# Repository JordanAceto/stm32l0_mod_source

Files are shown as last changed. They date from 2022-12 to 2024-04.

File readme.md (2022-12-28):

## Small STM32L0 based modulation source PCB

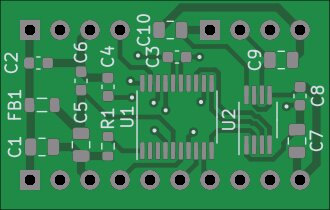
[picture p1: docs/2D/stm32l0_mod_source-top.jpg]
PCB front
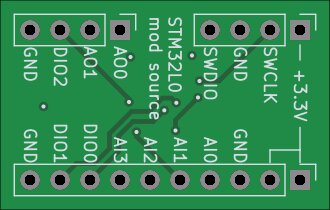
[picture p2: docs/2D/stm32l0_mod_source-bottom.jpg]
PCB rear
  

### Features:
- tiny pcb
- four analog inputs
- three digital input/outputs
- two analog outputs
- it can be configured for various modulation duties, such as
    - a dual LFO
    - a single ADSR
    - other things?
- drop it into various projects that need a small modulation source

### Status:

Task | Status |
---------|--------------|
Schematic capture | &#9745;
PCB layout | &#9745;
Test build | &#9745;
Safe to order boards| &#9745;

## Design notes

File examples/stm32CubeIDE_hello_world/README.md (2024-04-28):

# STM32CubeIDE "Hello World" example

## Brief
- This example is intended to exercise all of the IO pins on the board to verify everything works
- It is not intended as a real world project that does anything useful
- It does serve as an example of how to read and write analog and digital signals and write to the DAC
- It's an STM32CubeIDE project

## Description
This demo writes two low frequency analog ramp signals via the MCP4822 2-channel DAC.

Each ramp has:
- Variable frequency controlled by an analog signal in [0v, +3.3v]
- Variable offset controlled by an analog signal in [0v, +3.3v]
- The ability to "freeze" the ramp with a digital pin
  - Low = free running, high = frozen (the ramp stays at its current value until unfrozen)

The analog input signals can be driven by potentiometers wired as voltage dividers across the +3v3 rail, or any other convenient CV source that is in [0v, +3.3v].

## Pinouts

| PCB pin (silkscreen) | STM32 pin | Function |
|---|---|---|
| AI0 | PA0 | Rate A CV |
| AI1 | PA1 | Offset A CV |
| AI2 | PA2 | Rate B CV |
| AI3 | PA3 | Offset B CV |
| DOI0 | PA10 | Freeze A |
| DIO1 | PA9 | Freeze B |
| DIO2 | PA6 | CLK out (*f* = sample-rate / 2) |
| AO0 | - | Ramp A out, MCP4822 channel A |
| AO1 | - | Ramp B out, MCP4822 channel B |

### Schematic view of connections
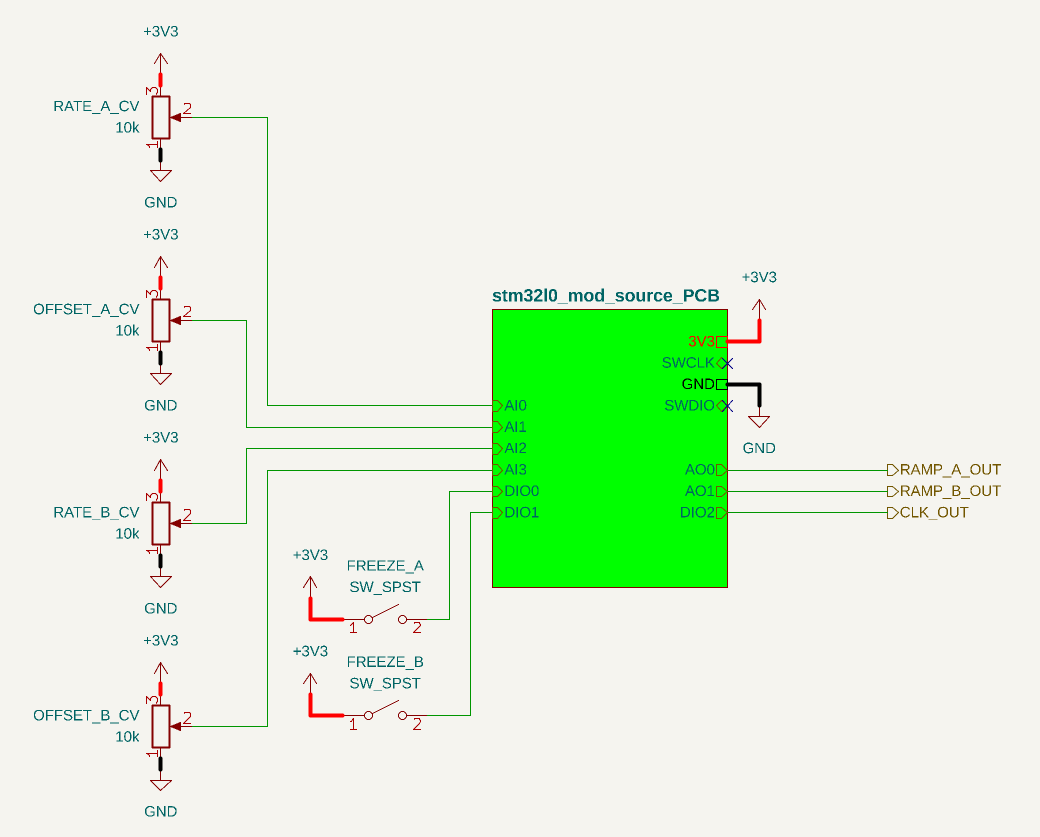
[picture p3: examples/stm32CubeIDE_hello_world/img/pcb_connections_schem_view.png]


### STM32CubeIDE view of connections
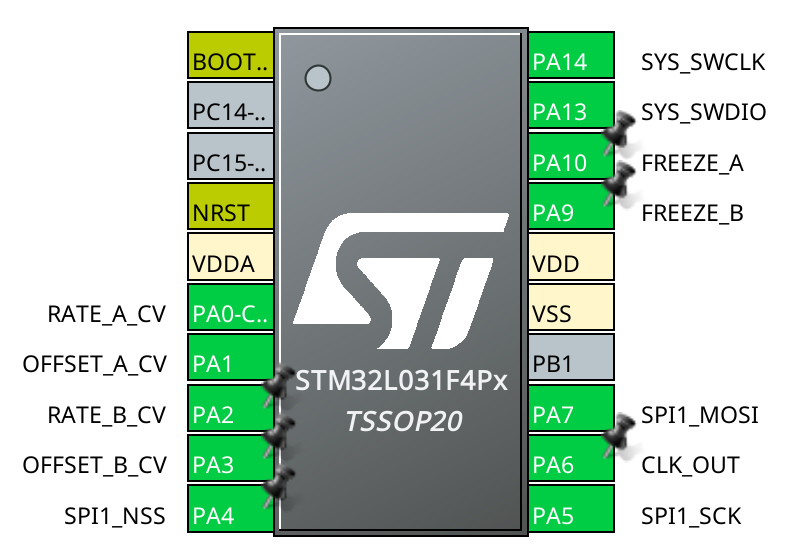
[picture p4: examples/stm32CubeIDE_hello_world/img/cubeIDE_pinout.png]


### Example breadboard setup
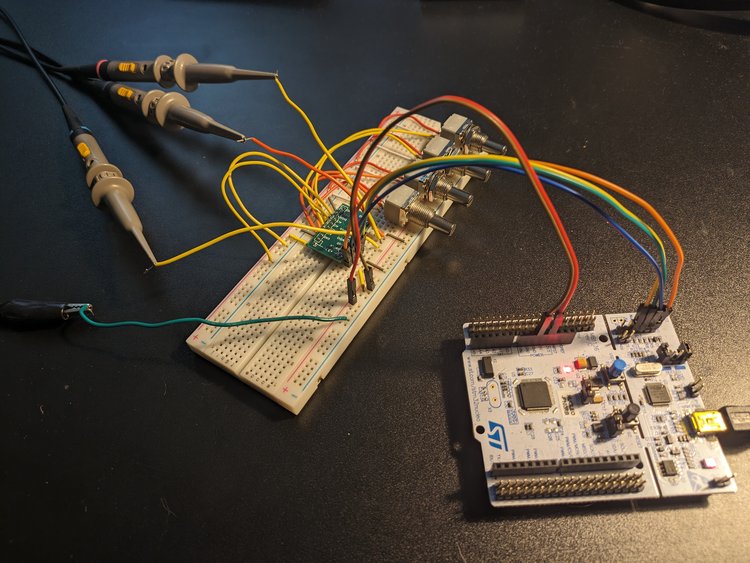
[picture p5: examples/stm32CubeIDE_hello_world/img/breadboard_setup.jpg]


## To verify
- Connect up the board as shown above, using a breadboard or other convenient method
- Flash the STM32L0 microcontroller with an STlink using the SWCLK and SWDIO pins
- Monitor the AO0, AO1, and DIO2 pins with an oscilloscope
- Verify that twiddling the pots alters the frequency and offset of the ramp signals
- Verify that pulling the FREEZE pins high freezes the associated ramp, and that the ramp resumes when the FREEZE pin is pulled low again 
- Verify that the CLK out on DIO2 is a square wave at 500Hz (default value)

Note that in the breadboard setup shown above, I am powering the board under test with a Nucleo acting as an STLink. This can be a convenient way to set up a minimal test.

Also note that I'm just using jumper wires jammed into the breadboard as the FREEZE switches.

## STM32CubeIDE Project Structure
This is a C++ CubeIDE project. The simplified project tree is shown below:

```
.
├── app
│   ├── app_main.cpp
│   └── app_main.hpp
├── lib
│   ├── analog_signals.cpp
│   ├── analog_signals.hpp
│   ├── MCP4822.cpp
│   └── MCP4822.hpp
├── Core
│   └── STM32 autogenerated Core .h and .c files
├── Drivers
│   └── STM32 provided CMSIS and driver files
├── L031F4Px_hello_world_example.ioc
└── STM32L031F4PX_FLASH.ld
```
User code is placed in `app` and `lib`. The `lib` directory contains user library files, `app` contains the main user application entry point. You shouldn't need to touch anything in `Core/` or `Drivers/` unless you want to change the pin or clock configuration.

The main application entry point function `app_main()` is called by the autogenerated `main()` function defined in `Core/Src/main.c` before the `while(1)` loop starts.

This allows us to keep our main application code separate from the CubeIDE autogenerated code. In my opinion this is cleaner than placing user code in the user-code-guards in the STM32 generated files.

### DMA note
The potentiometers are continuously read by the ADC and stored in a buffer via DMA. There are other ways to read the pots, this is one example of how you can scan a few pots.

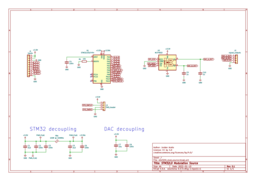
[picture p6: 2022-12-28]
docs/html_nav/images/cat_Schematic_stm32l0_mod_source-schematic.png

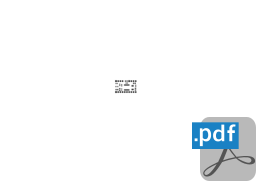
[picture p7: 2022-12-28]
docs/html_nav/images/cat_pdf_layers_stm32l0_mod_source-F_Mask.png

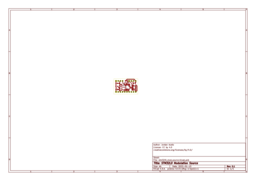
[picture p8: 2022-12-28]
docs/html_nav/images/cat_PCB_stm32l0_mod_source-F_Cu.png

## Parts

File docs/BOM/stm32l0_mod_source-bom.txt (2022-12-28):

Row	Description	Part	References	Value	Footprint	Quantity Per PCB	Status	Datasheet
1	Unpolarized capacitor	C	C2 C3 C4 C6 C8	100n	C_0603_1608Metric	5	 	~
2	Unpolarized capacitor	C	C9 C10	1u	C_0805_2012Metric	2	 	~
3	Unpolarized capacitor	C	C1 C5	2u2	C_0805_2012Metric	2	 	~
4	Unpolarized capacitor	C	C7	10u	C_0805_2012Metric	1	 	~
5	Ferrite bead, small symbol	FerriteBead_Small	FB1	100R @ 100MHz	L_0805_2012Metric	1	 	~
6	Generic connector, single row, 01x10, script generated (kicad-library-utils/schlib/autogen/connector/)	Conn_01x10	J1	inputs	PinHeader_1x10_P2.54mm_Vertical	1	 	~
7	Generic connector, single row, 01x04, script generated (kicad-library-utils/schlib/autogen/connector/)	Conn_01x04	J2 J3	signal_outputs	PinHeader_1x04_P2.54mm_Vertical	2	 	~
8	Resistor	R	R1	10k	R_0603_1608Metric	1	 	~
9	2-Channel 12-Bit D/A Converters with SPI Interface and Internal Reference (2.048V)	MCP4822	U2	MCP4822	MSOP-8_3x3mm_P0.65mm	1	 	http://ww1.microchip.com/downloads/en/DeviceDoc/20002249B.pdf
10	ARM Cortex-M0+ MCU, 16KB flash, 8KB RAM, 32MHz, 1.65-3.6V, 15 GPIO, TSSOP-20	STM32L031F4Px	U1	STM32L031F4Px	TSSOP-20_4.4x6.5mm_P0.65mm	1	 	http://www.st.com/st-web-ui/static/active/en/resource/technical/document/datasheet/DM00140359.pdf

Project info:
Schematic:	stm32l0_mod_source
Variant:	default
Revision:	0.1
Date:	2022-01-15
KiCad Version:	6.0.5+dfsg-1~bpo11+1
Statistics:
Component Groups:	10
Component Count:	17 (14 SMD/ 3 THT)
Fitted Components:	17 (14 SMD/ 3 THT)
Number of PCBs:	1
Total Components:	17

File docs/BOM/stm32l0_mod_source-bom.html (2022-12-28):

 | KiBot Bill of Materials
 | Schematic: stm32l0_mod_source Variant: default Revision: 0.1 Date: 2022-01-15 KiCad Version: 6.0.5+dfsg-1~bpo11+1 | Component Groups: 10 Component Count: 17 (14 SMD/ 3 THT) (per PCB) Fitted Components: 17 (14 SMD/ 3 THT) (per PCB) Number of PCBs: 1 Total Components: 17 (for 1 PCBs)
Row | Description | Part | References | Value | Footprint | Quantity Per PCB | Status | Datasheet
1 | Unpolarized capacitor | C | C2 C3 C4 C6 C8 | 100n | C_0603_1608Metric | 5 |  | ~
2 | Unpolarized capacitor | C | C9 C10 | 1u | C_0805_2012Metric | 2 |  | ~
3 | Unpolarized capacitor | C | C1 C5 | 2u2 | C_0805_2012Metric | 2 |  | ~
4 | Unpolarized capacitor | C | C7 | 10u | C_0805_2012Metric | 1 |  | ~
5 | Ferrite bead, small symbol | FerriteBead_Small | FB1 | 100R @ 100MHz | L_0805_2012Metric | 1 |  | ~
6 | Generic connector, single row, 01x10, script generated (kicad-library-utils/schlib/autogen/connector/) | Conn_01x10 | J1 | inputs | PinHeader_1x10_P2.54mm_Vertical | 1 |  | ~
7 | Generic connector, single row, 01x04, script generated (kicad-library-utils/schlib/autogen/connector/) | Conn_01x04 | J2 J3 | signal_outputs | PinHeader_1x04_P2.54mm_Vertical | 2 |  | ~
8 | Resistor | R | R1 | 10k | R_0603_1608Metric | 1 |  | ~
9 | 2-Channel 12-Bit D/A Converters with SPI Interface and Internal Reference (2.048V) | MCP4822 | U2 | MCP4822 | MSOP-8_3x3mm_P0.65mm | 1 |  | http://ww1.microchip.com/downloads/en/DeviceDoc/20002249B.pdf
10 | ARM Cortex-M0+ MCU, 16KB flash, 8KB RAM, 32MHz, 1.65-3.6V, 15 GPIO, TSSOP-20 | STM32L031F4Px | U1 | STM32L031F4Px | TSSOP-20_4.4x6.5mm_P0.65mm | 1 |  | http://www.st.com/st-web-ui/static/active/en/resource/technical/document/datasheet/DM00140359.pdf
Color reference:
KiCad Fields (default)
Generated Fields
User Fields
Empty Fields

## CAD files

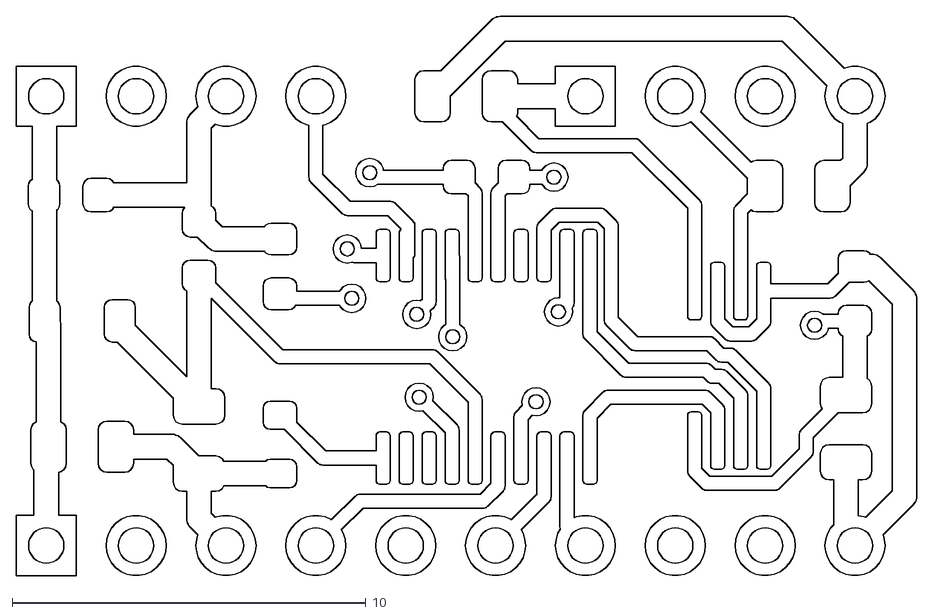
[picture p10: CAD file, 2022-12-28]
docs/CAD/stm32l0_mod_source-F_Cu.dxf
25.5 x 15.8

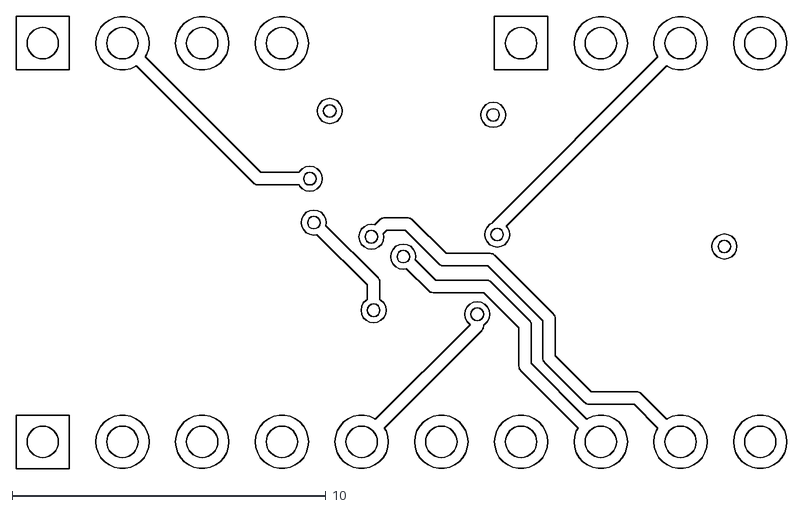
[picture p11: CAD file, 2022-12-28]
docs/CAD/stm32l0_mod_source-B_Cu.dxf
24.6 x 14.4

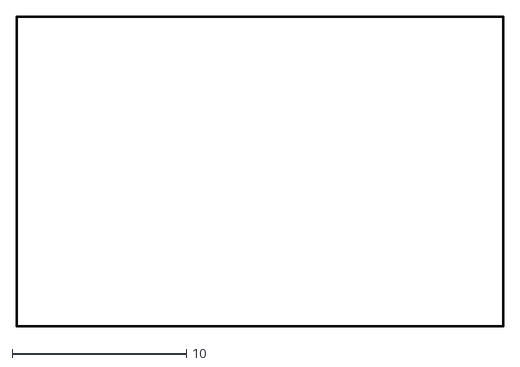
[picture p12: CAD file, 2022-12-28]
docs/CAD/stm32l0_mod_source-Edge_Cuts.dxf
28.0 x 17.8

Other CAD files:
docs/CAD/stm32l0_mod_source-B_Mask.dxf
docs/CAD/stm32l0_mod_source-B_Silkscreen.dxf
docs/CAD/stm32l0_mod_source-F_Mask.dxf
docs/CAD/stm32l0_mod_source-F_Silkscreen.dxf

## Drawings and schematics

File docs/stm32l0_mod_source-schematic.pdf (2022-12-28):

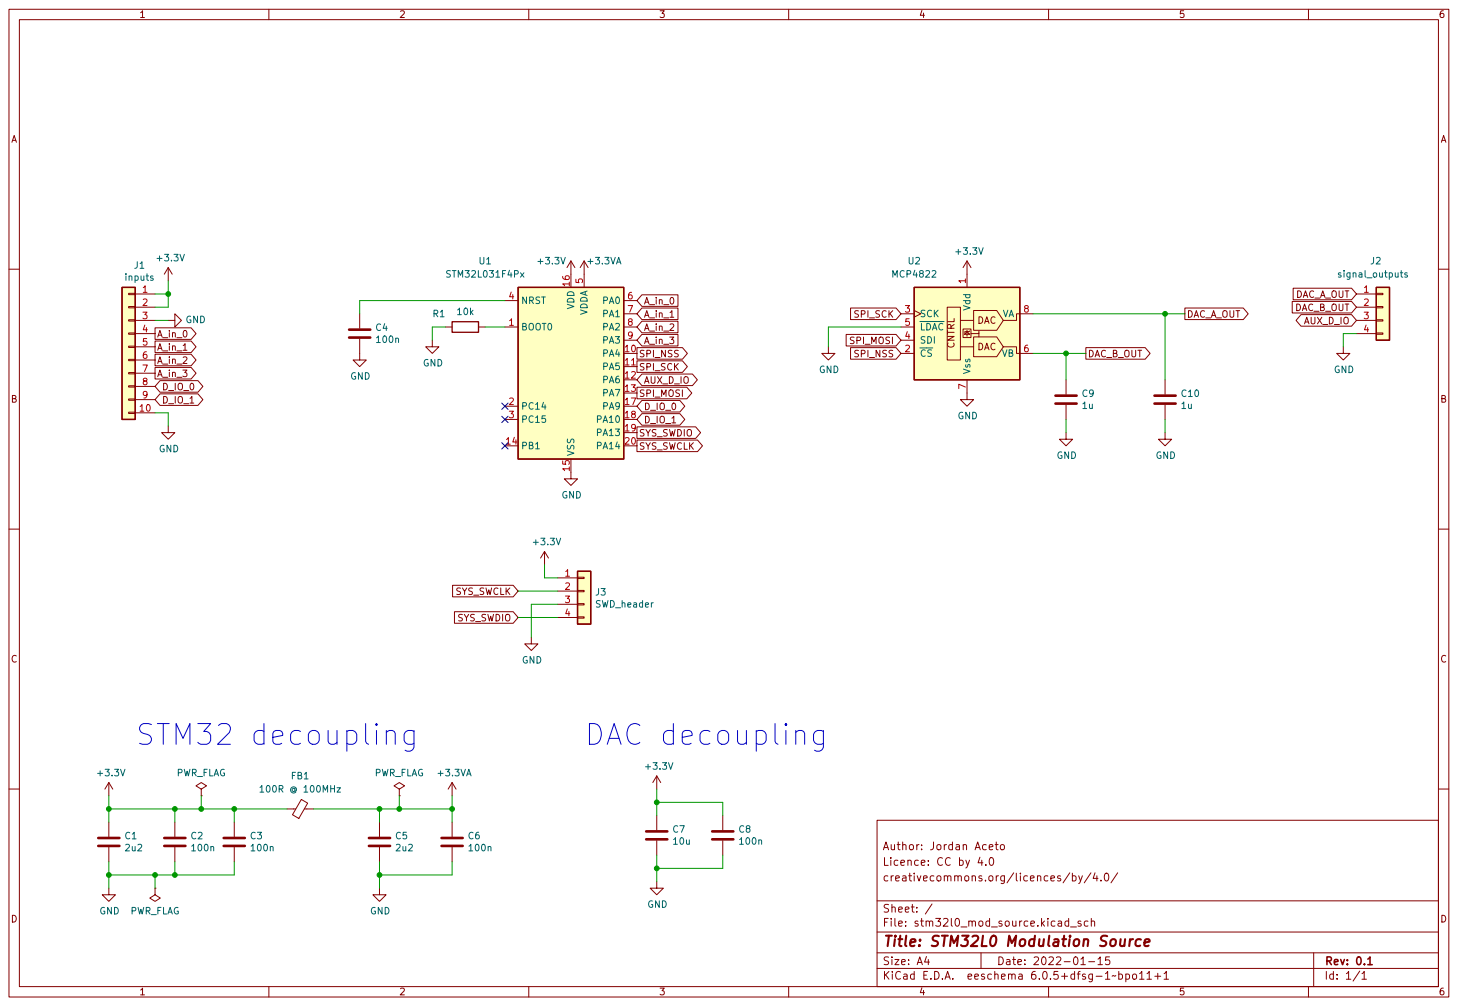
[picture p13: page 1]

1 ~{CS} 2 SCK 3 SDI 4 ~{LDAC} 5 VB 6 Vss 7 VA 8 U2 MCP4822 C10

Licence: CC by 4.0 Author: Jordan Aceto C1

File: stm32l0_mod_source.kicad_sch Sheet: / creativecommons.org/licences/by/4.0/

Id: 1/1 Title: STM32L0 Modulation Source

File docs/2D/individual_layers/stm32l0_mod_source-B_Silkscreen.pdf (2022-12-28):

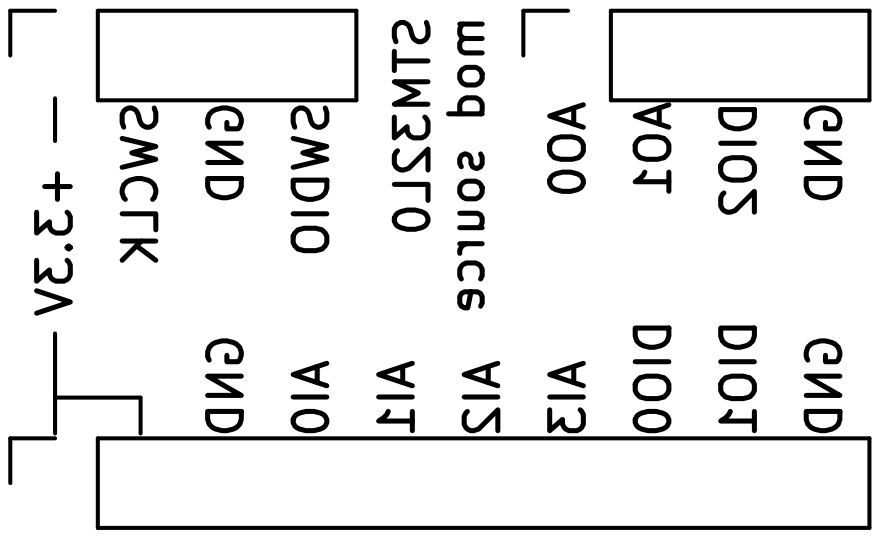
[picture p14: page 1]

AI2 DIO2 GND AI1 DIO1 GND GND STM32L0 mod source GNDAI0 AI3 SWDIO +3.3V AO1 DIO0 SWCLK AO0

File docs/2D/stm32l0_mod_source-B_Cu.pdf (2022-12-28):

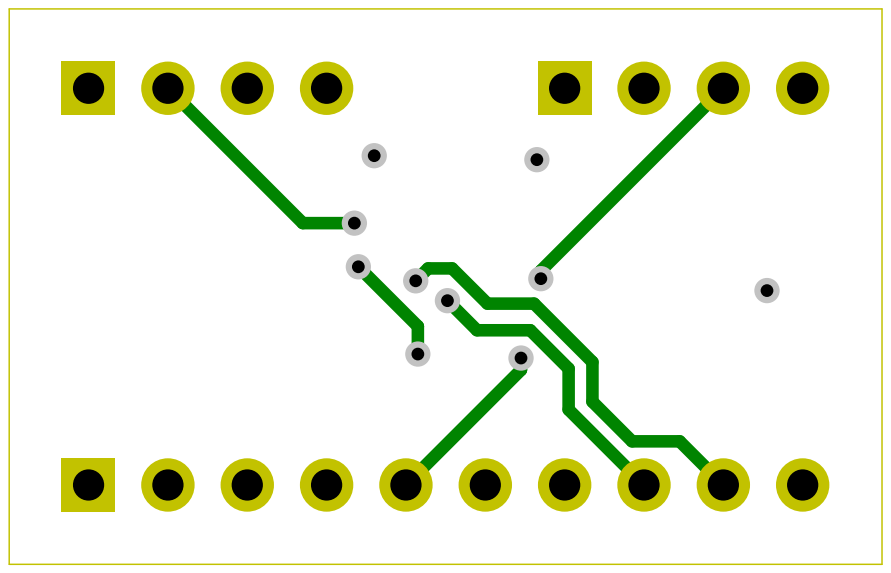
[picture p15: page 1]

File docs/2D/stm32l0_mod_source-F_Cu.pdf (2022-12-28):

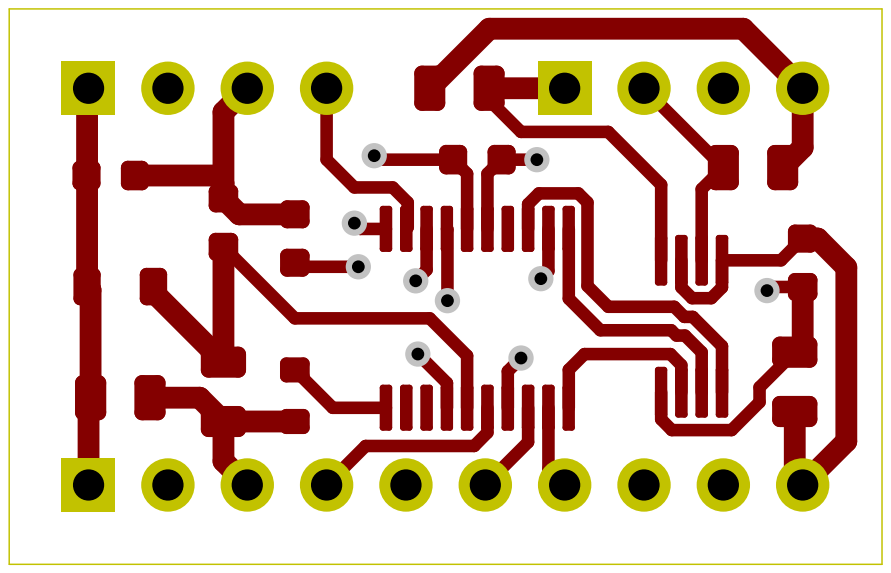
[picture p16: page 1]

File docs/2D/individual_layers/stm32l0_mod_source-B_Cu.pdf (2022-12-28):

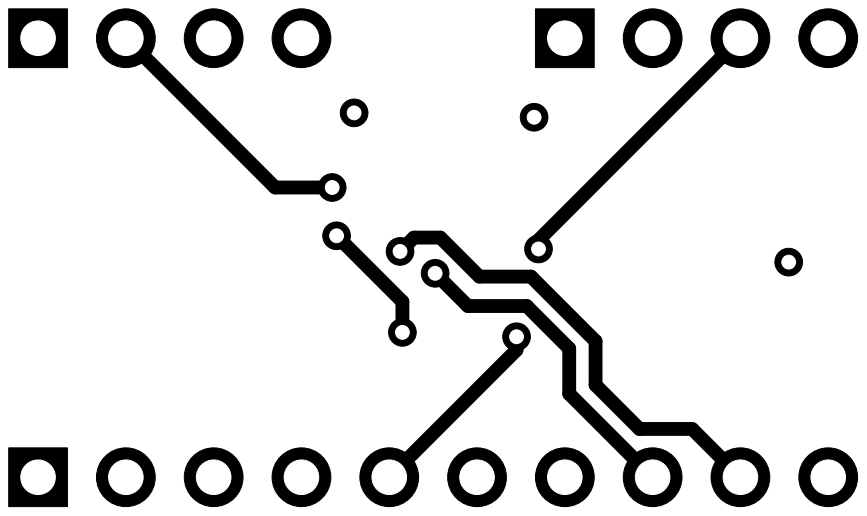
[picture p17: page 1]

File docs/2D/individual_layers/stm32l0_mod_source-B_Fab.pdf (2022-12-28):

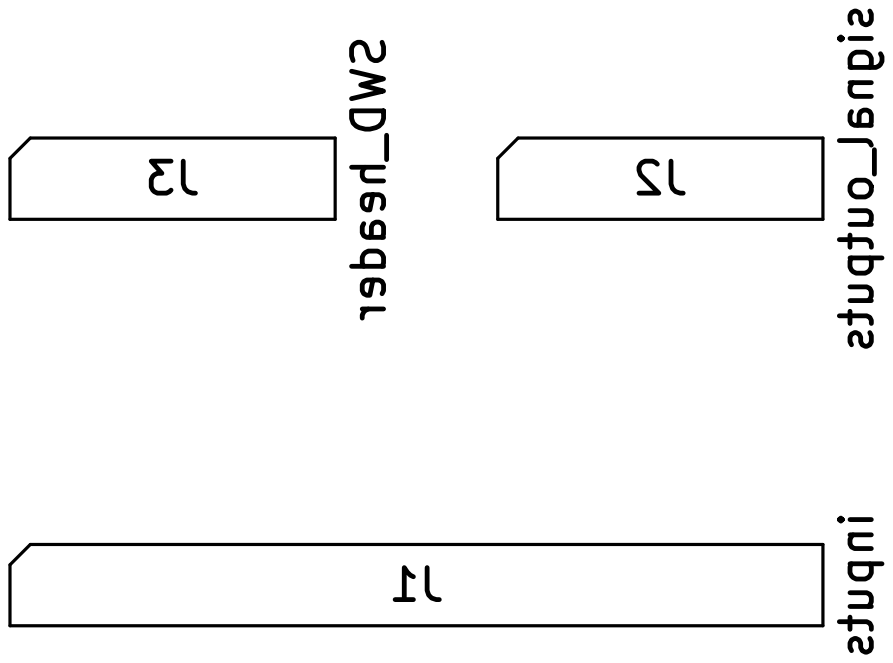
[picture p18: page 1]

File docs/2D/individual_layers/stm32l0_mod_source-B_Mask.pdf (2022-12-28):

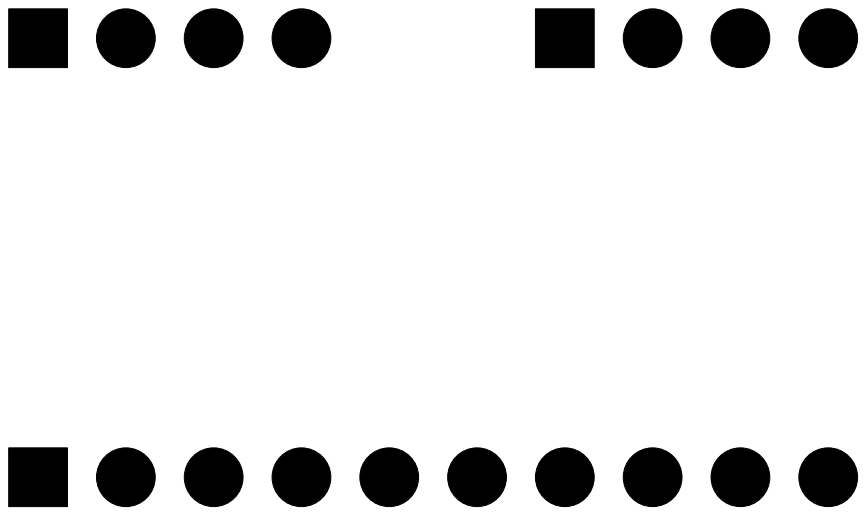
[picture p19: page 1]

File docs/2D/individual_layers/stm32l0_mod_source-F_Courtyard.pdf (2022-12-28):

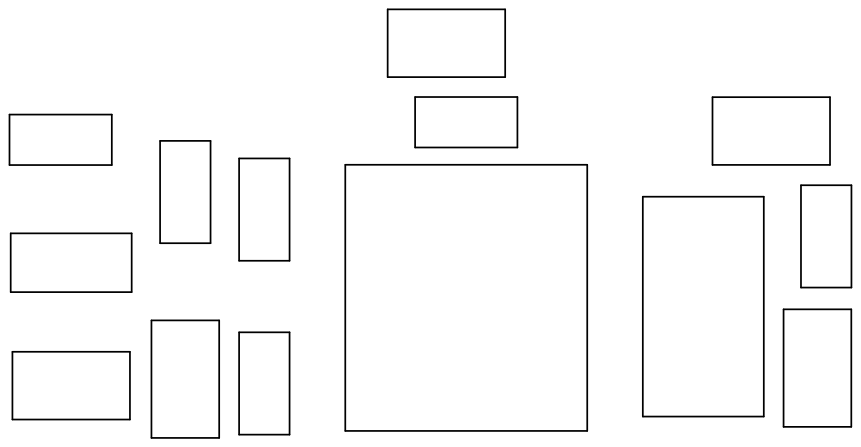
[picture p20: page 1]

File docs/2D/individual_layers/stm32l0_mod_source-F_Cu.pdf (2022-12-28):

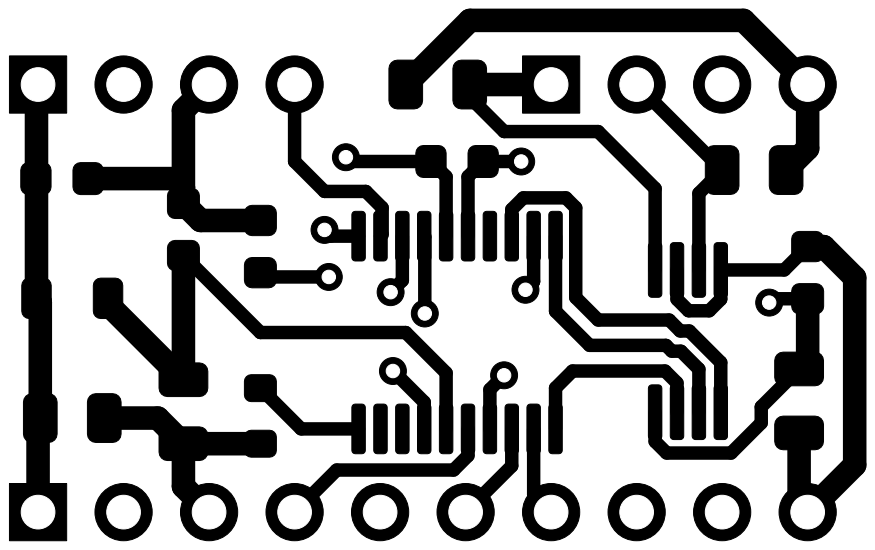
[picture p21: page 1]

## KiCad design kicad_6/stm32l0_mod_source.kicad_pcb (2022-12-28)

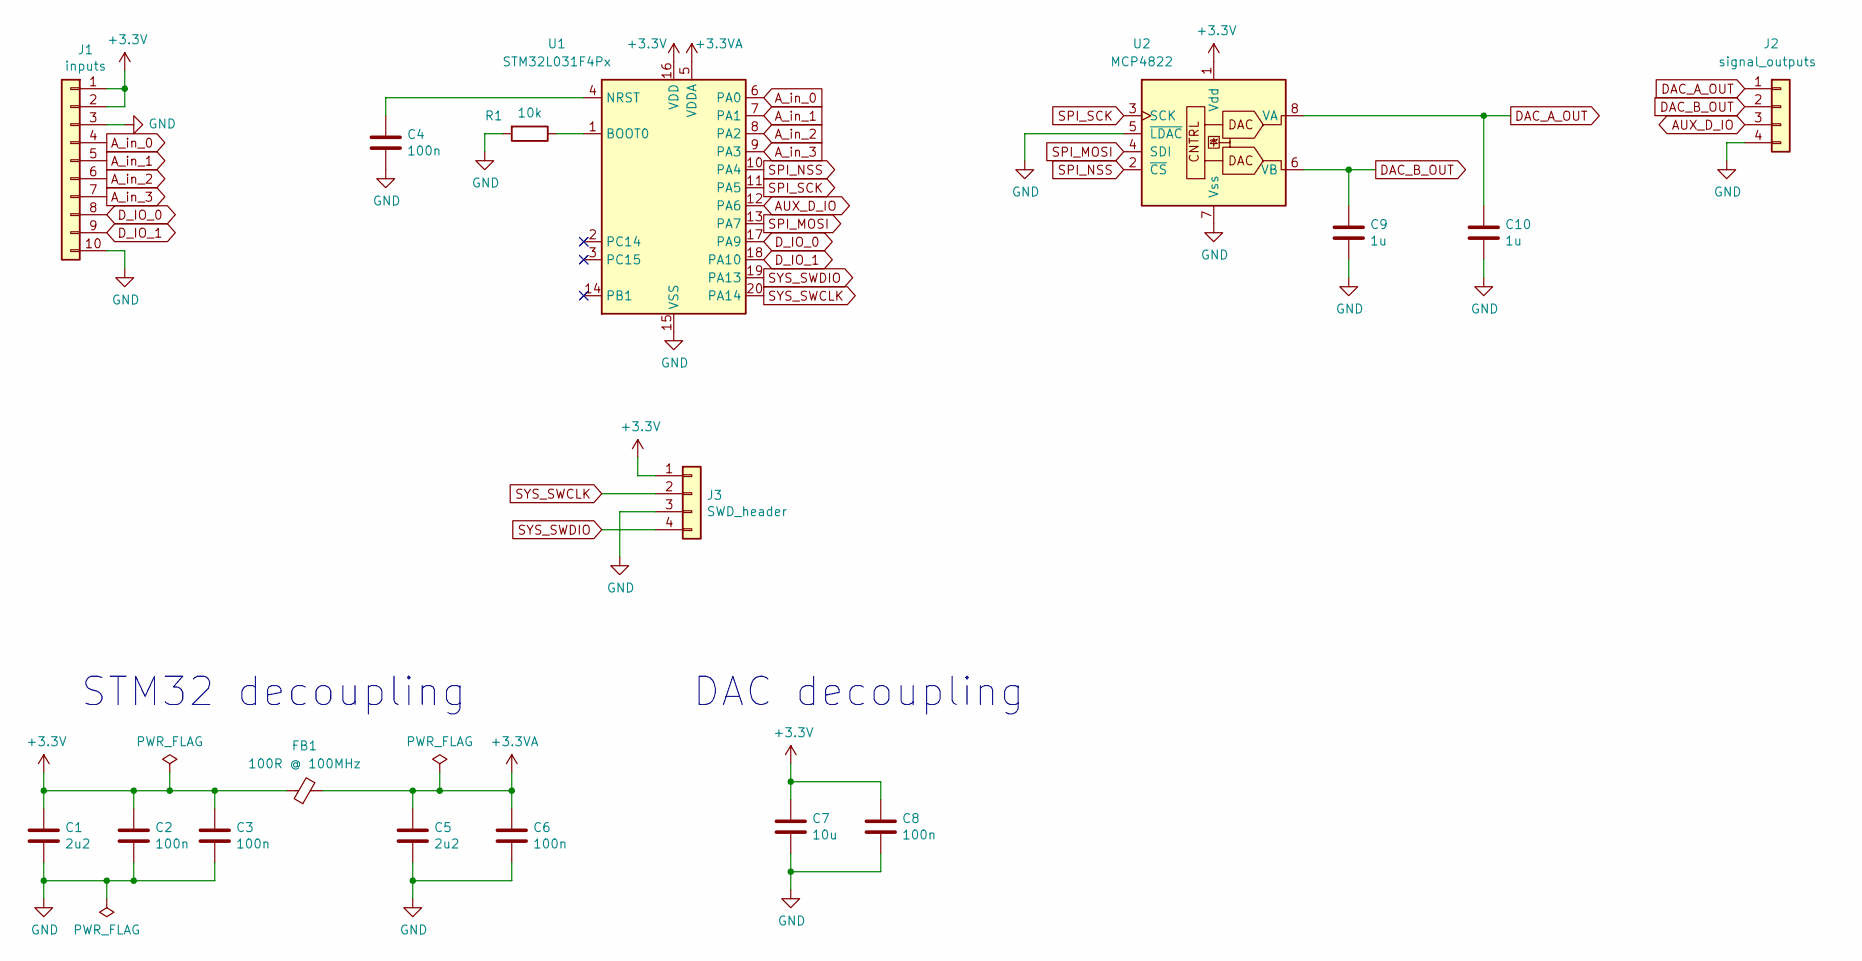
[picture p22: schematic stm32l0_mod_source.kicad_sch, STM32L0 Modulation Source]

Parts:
C1, C5: 2u2; C_0805_2012Metric
C2, C3, C4, C6, C8: 100n; C_0603_1608Metric
C7: 10u; C_0805_2012Metric
C9, C10: 1u; C_0805_2012Metric
FB1: 100R @ 100MHz; L_0805_2012Metric
J1: inputs; PinHeader_1x10_P2.54mm_Vertical
J2: signal_outputs; PinHeader_1x04_P2.54mm_Vertical
J3: SWD_header; PinHeader_1x04_P2.54mm_Vertical
R1: 10k; R_0603_1608Metric
U1: STM32L031F4Px; TSSOP-20_4.4x6.5mm_P0.65mm
U2: MCP4822; MSOP-8_3x3mm_P0.65mm

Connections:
+3.3V: C1.1, C2.1, C3.1, C7.1, C8.1, FB1.1, J1.1, J1.2, J3.1, U1.16 (VDD), U2.1 (Vdd)
+3.3VA: C5.1, C6.1, FB1.2, U1.5 (VDDA)
AUX_D_IO: J2.3, U1.12 (PA6)
A_in_0: J1.4, U1.6 (PA0)
A_in_1: J1.5, U1.7 (PA1)
A_in_2: J1.6, U1.8 (PA2)
A_in_3: J1.7, U1.9 (PA3)
DAC_A_OUT: C10.1, J2.1, U2.8 (VA)
DAC_B_OUT: C9.1, J2.2, U2.6 (VB)
D_IO_0: J1.8, U1.17 (PA9)
D_IO_1: J1.9, U1.18 (PA10)
GND: C1.2, C2.2, C3.2, C4.2, C5.2, C6.2, C7.2, C8.2, C9.2, C10.2, J1.3, J1.10, J2.4, J3.3, R1.2, U1.15 (VSS), U2.5 (~LDAC), U2.7 (Vss)
unnamed: C4.1, U1.4 (NRST)
unnamed: R1.1, U1.1 (BOOT0)
SPI_MOSI: U1.13 (PA7), U2.4 (SDI)
SPI_NSS: U1.10 (PA4), U2.2 (~CS)
SPI_SCK: U1.11 (PA5), U2.3 (SCK)
SYS_SWCLK: J3.2, U1.20 (PA14)
SYS_SWDIO: J3.4, U1.19 (PA13)

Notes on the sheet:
STM32 decoupling
DAC decoupling

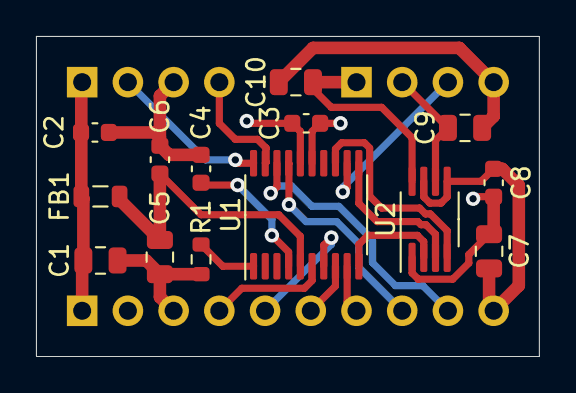
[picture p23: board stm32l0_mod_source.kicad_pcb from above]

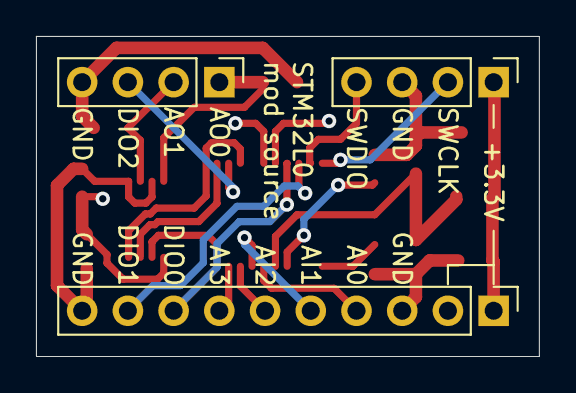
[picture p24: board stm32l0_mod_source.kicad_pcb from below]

Board: 4 copper layers, 27.9 x 17.8 mm, 17 parts (3 on the bottom side), 19 nets.

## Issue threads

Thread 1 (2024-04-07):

lfo example / hal reference?

bgapackage, 2024-04-07:
would it be possible to get an example of a basic lfo or HAL as a resource for this?
would be super helpful for learning how to use all the pins ect
thanks!

JordanAceto, 2024-04-07:
Hi there! Yes, this is a good idea. I have not added any examples mostly due to laziness. The way I typically use this board is to use it to try out some quick and dirty ideas to see if the L031 is sufficient for a project, and then port that code over to a project which has the same microcontroller on a larger board.

For example, these projects all use the same L031 uC (but not necessarily the same pinouts). I started development on this little breakout before committing to the "real" board:

- https://github.com/JordanAceto/whooshy_sound/tree/main/firmware
- https://github.com/JordanAceto/stereo_whooshy_sound/tree/master/firmware
- https://github.com/JordanAceto/msm_stereo_LPF/tree/main/firmware

Those projects all use the minimal CMSIS files and hand-rolled initialization code. I did it that way because I was in college at the time, and a big goal of the projects was educational value over efficiency. Today I would probably use CubeIDE for initialization and HAL functions, or maybe even use Rust.

Anyways, I'll see if I can whip something up to serve as an example or two. I am moving pretty slow on hobby projects atm, so it might not be right away.

Do you have an opinion on what format would be the most helpful? I think for starters I might do a basic CubeIDE project, this way people don't need to set up all the environment stuff on their own or mess with Makefiles/command line. I am going to assume that anyone interested in this has some experience with general STM32 development and can figure out how to set up the IDE/connect wires to the SWD port/etc.

Cheers and thanks for writing :)

bgapackage, 2024-04-07:
that would be great, i have some experience with cube ide and c/c++ and basic command line but thought it would be super helpful to see how u call the dac on this board and general approach to the hal from a c/c++ perspective! thanks

JordanAceto, 2024-04-28:
Hi there, I added an STM32CubeIDE project as a kind of hello-world for the board. It reads some pots and switches and output ramp waves on the two DAC channels. It's not much of a useful real-world project, but it hopefully gives you an idea of how you could read some pots and drive the DAC.
Let me know if this is in the ballpark of what you're looking for, suggestions (and pull requests!) are welcome.

bgapackage, 2024-04-28:
thanks so much!

JordanAceto, 2024-04-30:
Does that example give you enough to get started? If so we can close out this issue. It would be great to have more examples, but realistically I won't add more anytime soon. There are the three examples up in my earlier reply that could be pretty easily ported over to this board, these give you a "real LFO" with some nice features (multiple shapes, wave scan, set frequency directly).

bgapackage, 2024-04-30:
oh no it helps alot, your initital examples also helped alot once i got stuck in, thanks alot

Closed 2024-04-30.

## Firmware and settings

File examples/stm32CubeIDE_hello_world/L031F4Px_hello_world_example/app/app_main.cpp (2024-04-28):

#include "analog_signals.hpp"
#include "app_main.hpp"
#include "MCP4822.hpp"
#include "main.h"

/**
 * @brief Write an up-going ramp wave to the DAC as a demo of the hardware
 *
 * The ramp has variable rate and DC offset. The purpose of this is just to dempnstrate that the DAC and ADC are
 * both working, this is not expected to be useful for anything beyond verifying that the PCB is working. The template
 * function approach used here is kind of goofy, and is only used to keep the demo simple while avoiding repeated code.
 * I would not use this approach in a "real" application.
 *
 * This function must be regularly called at some fixed interval which determines the sample rate. This is a very
 * crude form of Direct Digital Synthesis.
 *
 * @tparam Channel: the MCP4822 DAC channel to write to
 * @tparam Rate: the Analog signal to use for the rate control
 * @tparam Offset: the Analog signal to use for the variable DC offset
 *
 * @pre all system initialization is complete
 *
 * @post an upgoing ramp voltage signal will appear at the output of the given DAC channel when this function is
 *    called repeatedly at fixed intervals
 */
template <MCP4822::Channel Channel, AnalogSignals::Channel Rate, AnalogSignals::Channel Offset>
void demo_ramp_tick()
{
  static uint16_t ramp = 0;

  // scale the rate control so the ramp frequency is easy to see with scope or LED, empirically scaled, tweak away
  uint16_t incr = (AnalogSignals::get(Rate) / 50u) + 1u;
  ramp += incr;

  // reset the ramp once we hit the top of the sawtooth pattern
  if (MCP4822::FULL_SCALE < ramp)
  {
    ramp = 0;
  }

  // add a variable DC offset to the ramp, we can push the ramp up and down with this offset
  int offset = AnalogSignals::get(Offset) - (AnalogSignals::FULL_SCALE / 2);
  int offset_ramp = ramp + offset;

  // clamp the offset ramp so it stays within the DAC range
  if (offset_ramp < 0)
  {
    offset_ramp = 0;
  }
  if (MCP4822::FULL_SCALE < offset_ramp)
  {
    offset_ramp = MCP4822::FULL_SCALE;
  }

  MCP4822::write((uint16_t)offset_ramp, Channel);
}

void app_main()
{
  // start the ADC, it will continuously convert all the channels after calling this
  AnalogSignals::start_DMA();

  while (1)
  {
    if (!HAL_GPIO_ReadPin(FREEZE_A_GPIO_Port, FREEZE_A_Pin))
    {
      demo_ramp_tick<MCP4822::Channel::A, AnalogSignals::Channel::RATE_A, AnalogSignals::Channel::OFFSET_A>();
    }

    if (!HAL_GPIO_ReadPin(FREEZE_B_GPIO_Port, FREEZE_B_Pin))
    {
      demo_ramp_tick<MCP4822::Channel::B, AnalogSignals::Channel::RATE_B, AnalogSignals::Channel::OFFSET_B>();
    }

    // generate a square wave on the CLK out pin at 1/2 the sample rate
    HAL_GPIO_TogglePin(CLK_OUT_GPIO_Port, CLK_OUT_Pin);

    // the delay time here is a crude way of setting the sample rate for the demo, the HAL_Delay(n) is
    // "at least n milliseconds", so to get 1msec delay we user zero here, play around with this if desired
    HAL_Delay(0);
  }
}

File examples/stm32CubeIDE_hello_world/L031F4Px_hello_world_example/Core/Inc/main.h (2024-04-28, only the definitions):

#define RATE_A_CV_Pin GPIO_PIN_0
#define RATE_A_CV_GPIO_Port GPIOA
#define OFFSET_A_CV_Pin GPIO_PIN_1
#define OFFSET_A_CV_GPIO_Port GPIOA
#define RATE_B_CV_Pin GPIO_PIN_2
#define RATE_B_CV_GPIO_Port GPIOA
#define OFFSET_B_CV_Pin GPIO_PIN_3
#define OFFSET_B_CV_GPIO_Port GPIOA
#define SPI1_NSS_Pin GPIO_PIN_4
#define SPI1_NSS_GPIO_Port GPIOA
#define CLK_OUT_Pin GPIO_PIN_6
#define CLK_OUT_GPIO_Port GPIOA
#define FREEZE_B_Pin GPIO_PIN_9
#define FREEZE_B_GPIO_Port GPIOA
#define FREEZE_A_Pin GPIO_PIN_10
#define FREEZE_A_GPIO_Port GPIOA

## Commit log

2021-06-12 refine pcb
    [SPI_DAC.sch, microcontroller.sch, power_supply.sch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]
2021-06-12 add interactivce BOM
2021-06-12 add pdf schematic
2021-06-12 add gerbers
    [stm32l0_mod_source-B_Mask.gbs, stm32l0_mod_source-B_Paste.gbp, stm32l0_mod_source-B_SilkS.gbo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]
2022-12-28 Shrink board, new layout
    [SPI_DAC.sch, microcontroller.sch, power_supply.sch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]
2024-04-28 Add STM32CubeIDE basic example to exercise and verify the board

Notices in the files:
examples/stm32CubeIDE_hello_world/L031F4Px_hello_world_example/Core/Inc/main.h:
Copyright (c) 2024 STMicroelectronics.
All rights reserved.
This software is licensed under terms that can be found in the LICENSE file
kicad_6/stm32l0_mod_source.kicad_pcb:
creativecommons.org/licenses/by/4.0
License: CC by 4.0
